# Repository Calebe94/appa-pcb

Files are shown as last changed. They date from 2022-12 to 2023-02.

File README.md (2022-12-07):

# Appa keyboard - PCB

This keyboard is inspired by [Plaid](https://github.com/AntonioPelayo/plaid-through-hole-keyboard) and [Gherkin Apls 1.1](https://www.40percent.club/2017/08/gherkin-alps-11.html).

I'm using white APLS switches for this project and Arduino Pro Mini as the core microcontroller.

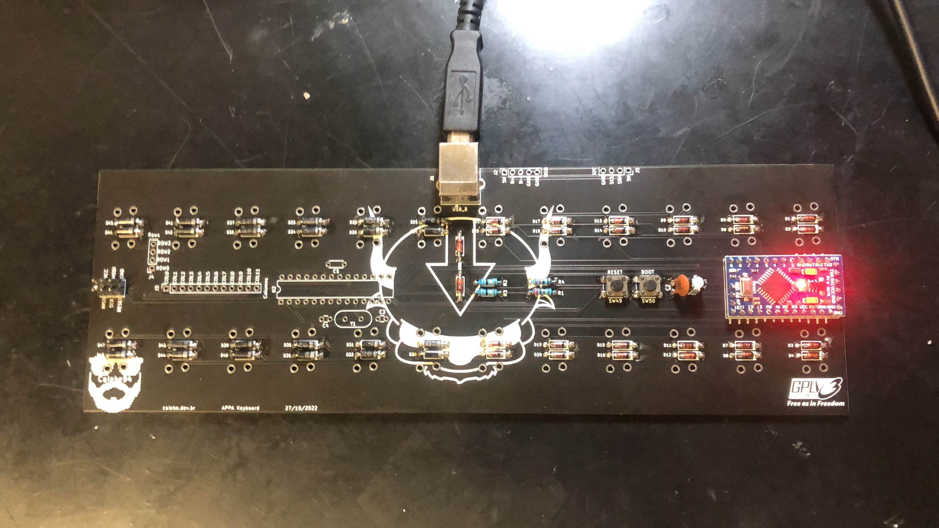
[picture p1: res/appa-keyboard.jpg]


## Dependencies

* [Kicad 6+](https://packages.debian.org/bookworm/kicad).

## Symbols and Footprints

* I'm using an slightly modded version of [ARDUINO PRO MINI](https://www.snapeda.com/parts/Arduino%20Pro%20Mini/Arduino/view-part/?t=arduino+pro+mini&welcome=home) from [SnapEDA](https://www.snapeda.com). (I've just added a couple of pins at the bottom at the board because my PRO Mini uses the TQFP and QFN/MLF package of the ATMEGA328p);
* For the ALPS switches and the diodes I'm using the [keyboard_parts.pretty](https://github.com/tmk/keyboard_parts.pretty) footprints;
* As for the rest I'm using the KiCAD's stock footprints.

## Schematic

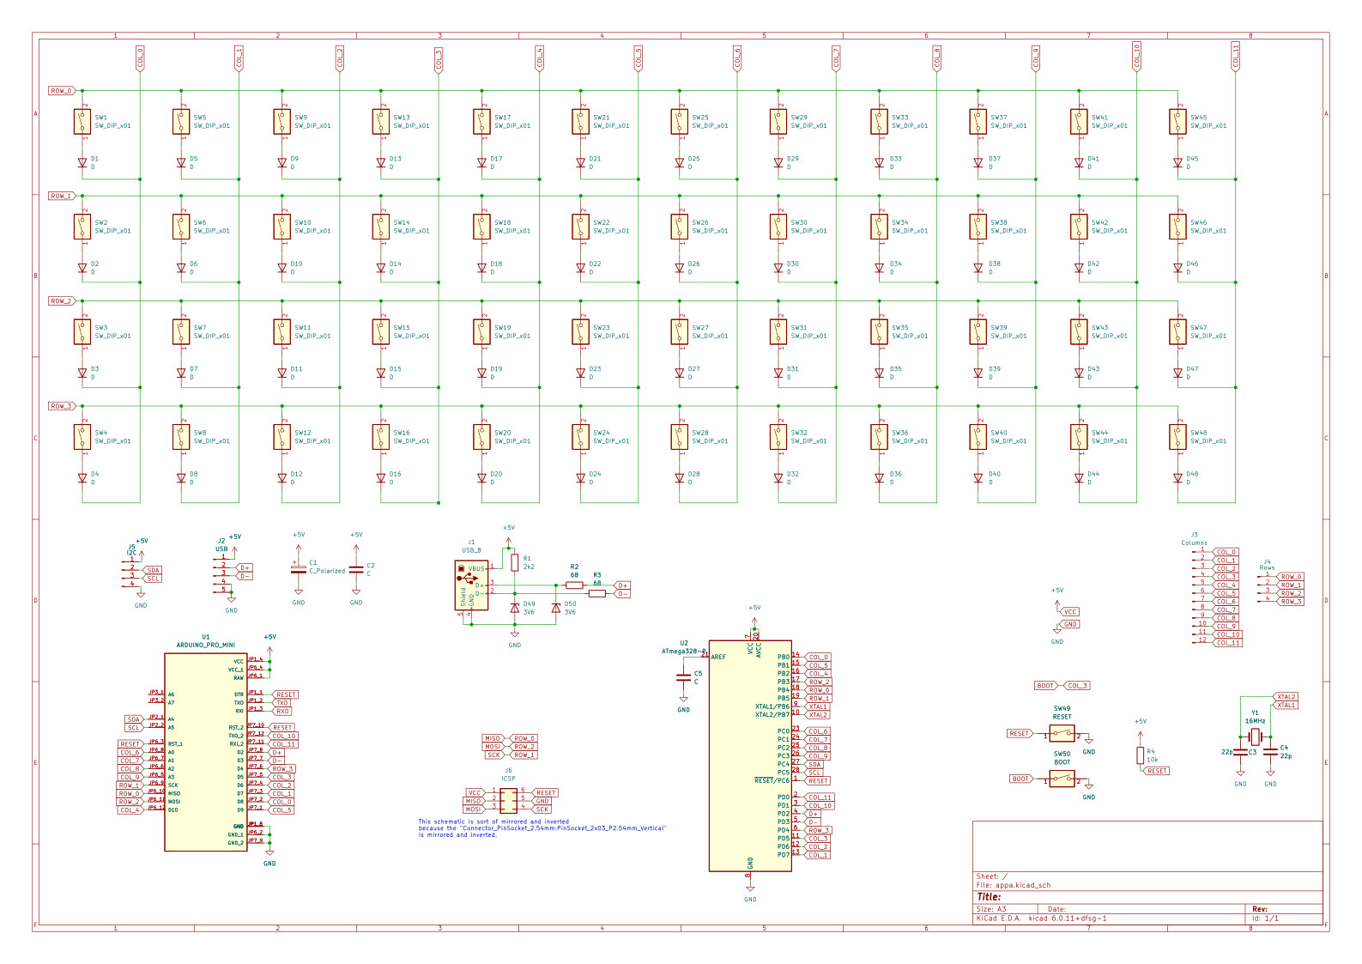
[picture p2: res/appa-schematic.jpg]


# License

All software is covered under [GNU General Public License v3.0](https://www.gnu.org/licenses/gpl-3.0.en.html).

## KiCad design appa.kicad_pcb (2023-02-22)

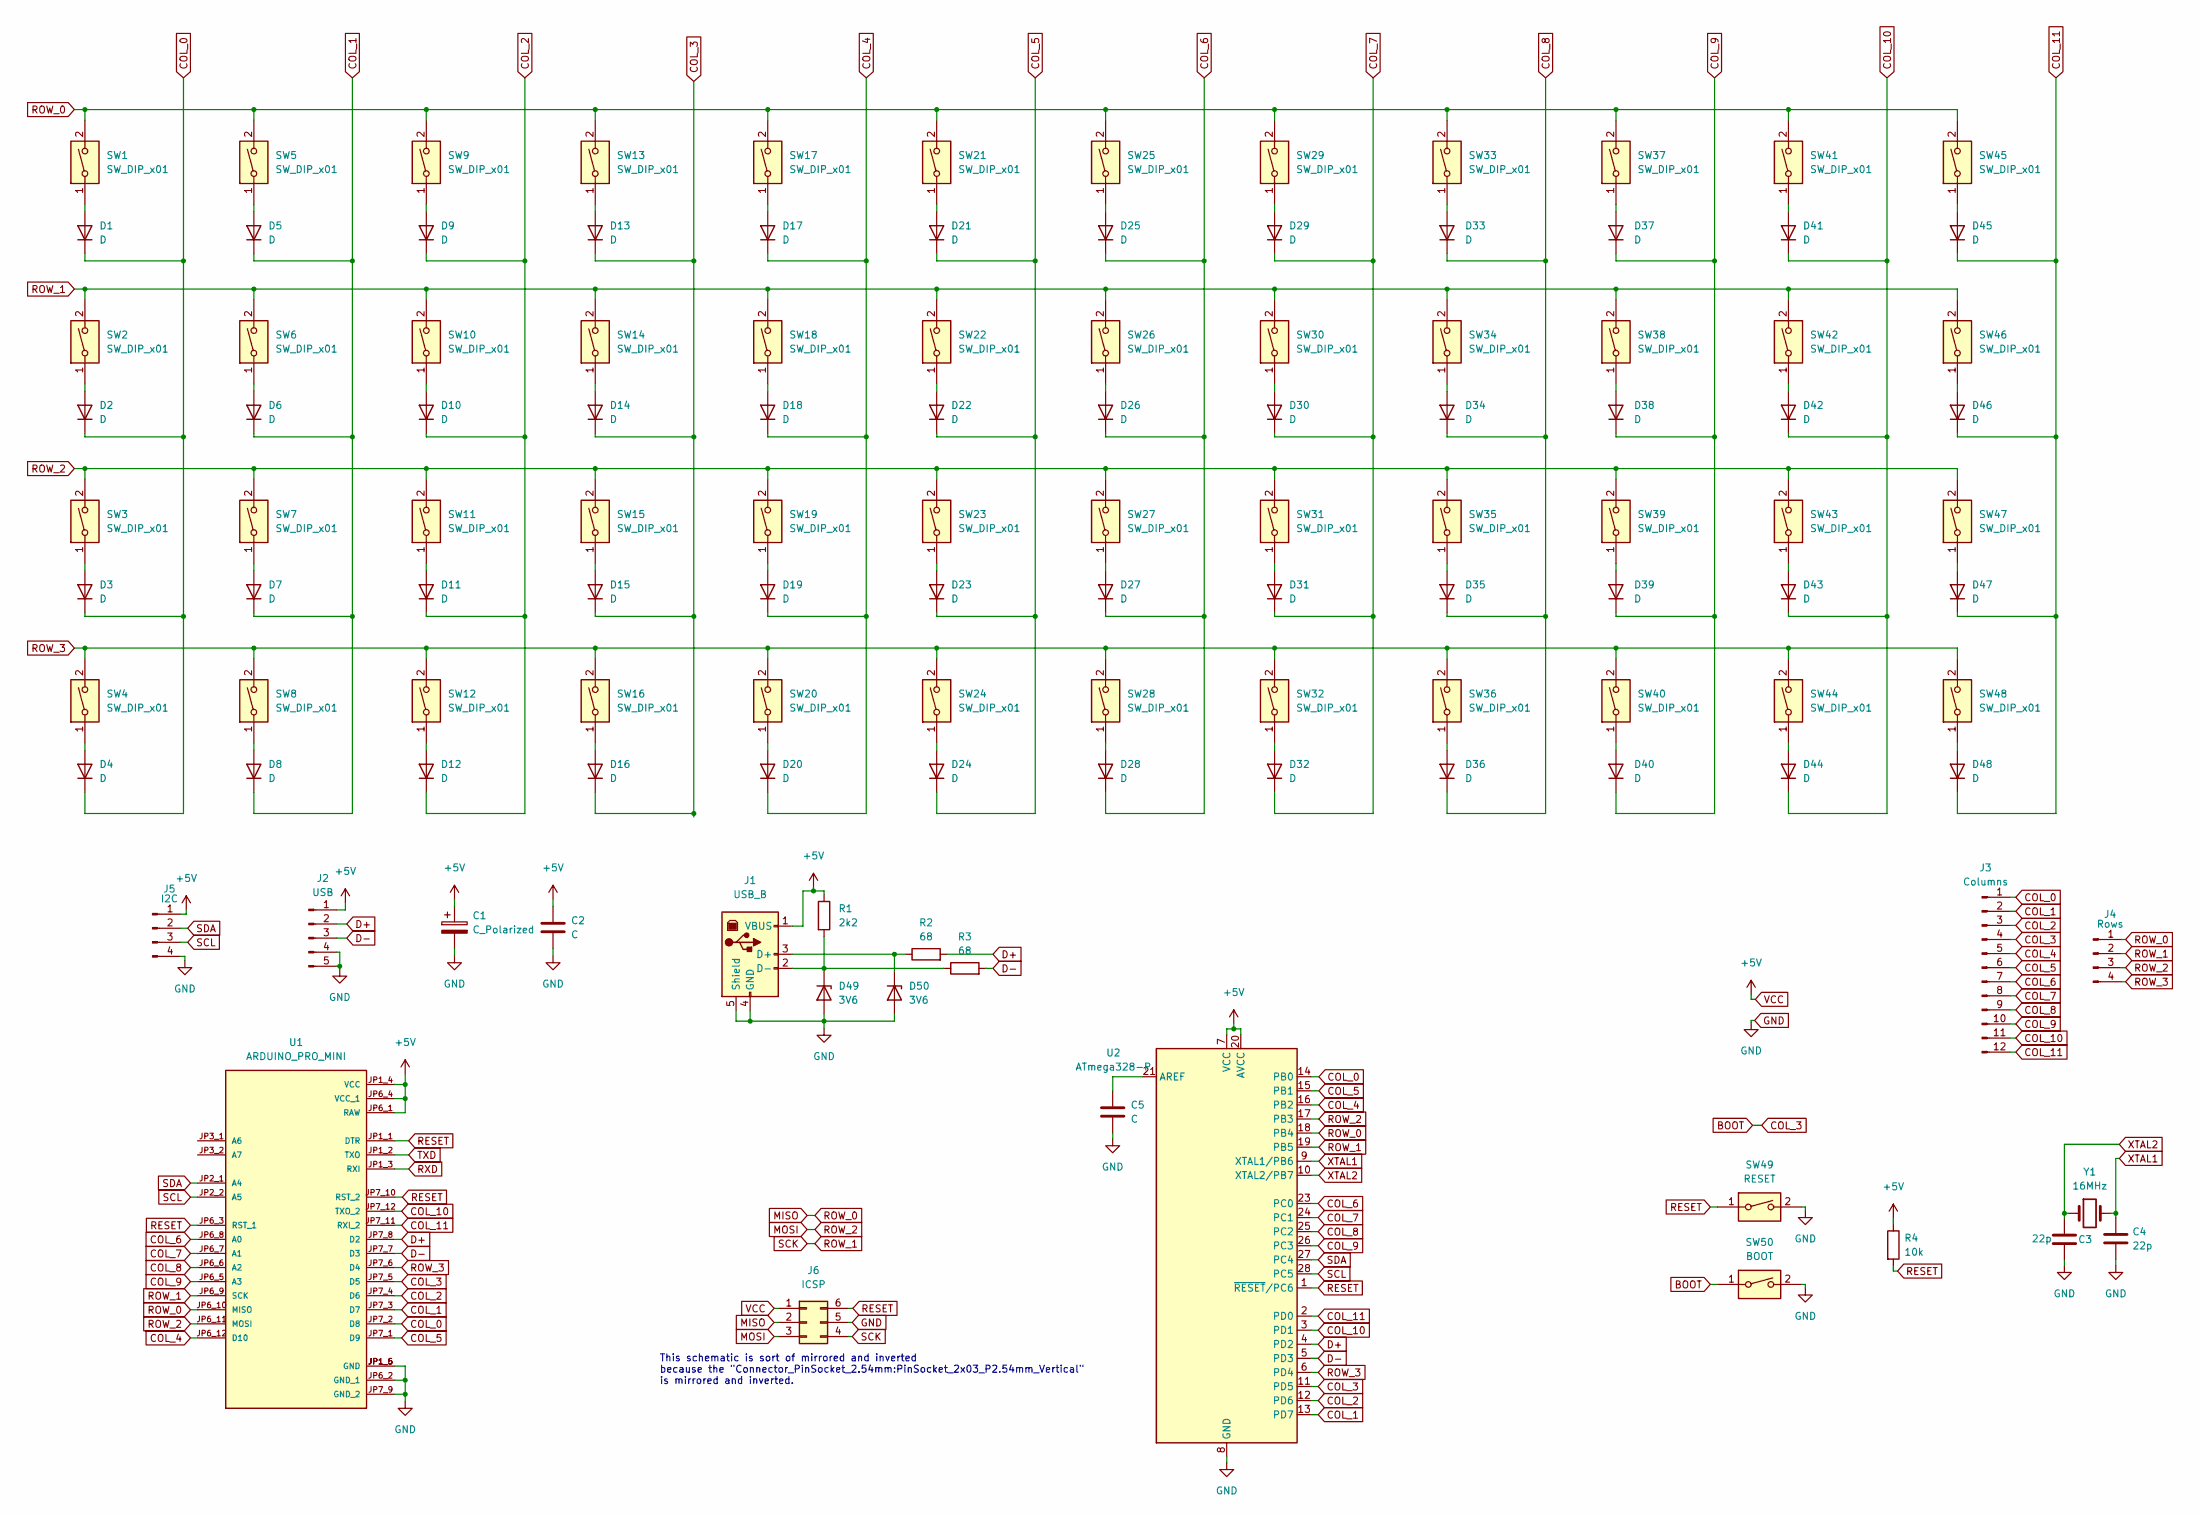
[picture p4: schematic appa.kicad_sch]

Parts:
C1: C_Polarized; CP_Radial_D4.0mm_P1.50mm
C2: C; C_Disc_D3.0mm_W1.6mm_P2.50mm
C3, C4: 22p; C_Disc_D3.0mm_W1.6mm_P2.50mm
C5: C; C_Disc_D4.3mm_W1.9mm_P5.00mm
D1, D2, D3, D4, D5, D6, D7, D8, D9, D10, D11, D12, D13, D14, D15, D16, D17, D18, D19, D20, D21, D22, D23, D24, D25, D26, D27, D28, D29, D30, D31, D32, D33, D34, D35, D36, D37, D38, D39, D40, D41, D42, D43, D44, D45, D46, D47, D48: D; D_SOD123_axial
D49, D50: 3V6; D_SOD123_axial
J1: USB_B; USB_B_OST_USB-B1HSxx_Horizontal
J2: USB; PinSocket_1x05_P2.54mm_Vertical
J3: Columns; PinSocket_1x12_P2.54mm_Vertical
J4: Rows; PinSocket_1x04_P2.54mm_Vertical
J5: I2C; PinSocket_1x04_P2.54mm_Vertical
J6: ICSP; PinSocket_2x03_P2.54mm_Vertical
R1: 2k2; R_Axial_DIN0204_L3.6mm_D1.6mm_P7.62mm_Horizontal
R2, R3: 68; R_Axial_DIN0204_L3.6mm_D1.6mm_P7.62mm_Horizontal
R4: 10k; R_Axial_DIN0204_L3.6mm_D1.6mm_P7.62mm_Horizontal
SW1, SW2, SW3, SW4, SW5, SW6, SW7, SW8, SW9, SW10, SW11, SW12, SW13, SW14, SW15, SW16, SW17, SW18, SW19, SW20, SW21, SW22, SW23, SW24, SW25, SW26, SW27, SW28, SW29, SW30, SW31, SW32, SW33, SW34, SW35, SW36, SW37, SW38, SW39, SW40, SW41, SW42, SW43, SW44, SW45, SW46, SW47, SW48: SW_DIP_x01; ALPS_SKCM
SW49: RESET; SW_PUSH_6mm
SW50: BOOT; SW_PUSH_6mm
U1: ARDUINO_PRO_MINI; MODULE_ARDUINO_PRO_MINI; PARTREV N/A
U2: ATmega328-P; DIP-28_W7.62mm
Y1: 16MHz; Crystal_HC18-U_Vertical

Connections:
BOOT: D13.1 (K), D14.1 (K), D15.1 (K), D16.1 (K), J3.4, SW50.1, U1.JP7_5 (D5), U2.11 (PD5)
COL_0: D1.1 (K), D2.1 (K), D3.1 (K), D4.1 (K), J3.1, U1.JP7_2 (D8), U2.14 (PB0)
COL_1: D5.1 (K), D6.1 (K), D7.1 (K), D8.1 (K), J3.2, U1.JP7_3 (D7), U2.13 (PD7)
COL_2: D9.1 (K), D10.1 (K), D11.1 (K), D12.1 (K), J3.3, U1.JP7_4 (D6), U2.12 (PD6)
COL_4: D17.1 (K), D18.1 (K), D19.1 (K), D20.1 (K), J3.5, U1.JP6_12 (D10), U2.16 (PB2)
COL_5: D21.1 (K), D22.1 (K), D23.1 (K), D24.1 (K), J3.6, U1.JP7_1 (D9), U2.15 (PB1)
COL_6: D25.1 (K), D26.1 (K), D27.1 (K), D28.1 (K), J3.7, U1.JP6_8 (A0), U2.23 (PC0)
COL_7: D29.1 (K), D30.1 (K), D31.1 (K), D32.1 (K), J3.8, U1.JP6_7 (A1), U2.24 (PC1)
COL_8: D33.1 (K), D34.1 (K), D35.1 (K), D36.1 (K), J3.9, U1.JP6_6 (A2), U2.25 (PC2)
COL_9: D37.1 (K), D38.1 (K), D39.1 (K), D40.1 (K), J3.10, U1.JP6_5 (A3), U2.26 (PC3)
COL_10: D41.1 (K), D42.1 (K), D43.1 (K), D44.1 (K), J3.11, U1.JP7_12 (TXO_2), U2.3 (PD1)
COL_11: D45.1 (K), D46.1 (K), D47.1 (K), D48.1 (K), J3.12, U1.JP7_11 (RXI_2), U2.2 (PD0)
D+: J2.2, R2.2, U1.JP7_8 (D2), U2.4 (PD2)
D-: J2.3, R3.2, U1.JP7_7 (D3), U2.5 (PD3)
GND: C1.2, C2.2, C3.2, C4.2, C5.2, D49.2 (A), D50.2 (A), J1.4 (GND), J1.5 (Shield), J2.4, J2.5, J5.4, J6.5, SW49.2, SW50.2, U1.JP1_5 (GND), U1.JP1_6 (GND), U1.JP6_2 (GND_1), U1.JP7_9 (GND_2), U2.8 (GND), U2.22 (GND)
MISO: J4.1, J6.2, SW1.2, SW5.2, SW9.2, SW13.2, SW17.2, SW21.2, SW25.2, SW29.2, SW33.2, SW37.2, SW41.2, SW45.2, U1.JP6_10 (MISO), U2.18 (PB4)
MOSI: J4.3, J6.3, SW3.2, SW7.2, SW11.2, SW15.2, SW19.2, SW23.2, SW27.2, SW31.2, SW35.2, SW39.2, SW43.2, SW47.2, U1.JP6_11 (MOSI), U2.17 (PB3)
unnamed: C5.1, U2.21 (AREF)
unnamed: D1.2 (A), SW1.1
unnamed: D2.2 (A), SW2.1
unnamed: D3.2 (A), SW3.1
unnamed: D4.2 (A), SW4.1
unnamed: D5.2 (A), SW5.1
unnamed: D6.2 (A), SW6.1
unnamed: D7.2 (A), SW7.1
unnamed: D8.2 (A), SW8.1
unnamed: D9.2 (A), SW9.1
unnamed: D10.2 (A), SW10.1
unnamed: D11.2 (A), SW11.1
unnamed: D12.2 (A), SW12.1
unnamed: D13.2 (A), SW13.1
unnamed: D14.2 (A), SW14.1
unnamed: D15.2 (A), SW15.1
unnamed: D16.2 (A), SW16.1
unnamed: D17.2 (A), SW17.1
unnamed: D18.2 (A), SW18.1
unnamed: D19.2 (A), SW19.1
unnamed: D20.2 (A), SW20.1
unnamed: D21.2 (A), SW21.1
unnamed: D22.2 (A), SW22.1
unnamed: D23.2 (A), SW23.1
unnamed: D24.2 (A), SW24.1
unnamed: D25.2 (A), SW25.1
unnamed: D26.2 (A), SW26.1
unnamed: D27.2 (A), SW27.1
unnamed: D28.2 (A), SW28.1
unnamed: D29.2 (A), SW29.1
unnamed: D30.2 (A), SW30.1
unnamed: D31.2 (A), SW31.1
unnamed: D32.2 (A), SW32.1
unnamed: D33.2 (A), SW33.1
unnamed: D34.2 (A), SW34.1
unnamed: D35.2 (A), SW35.1
unnamed: D36.2 (A), SW36.1
unnamed: D37.2 (A), SW37.1
unnamed: D38.2 (A), SW38.1
unnamed: D39.2 (A), SW39.1
unnamed: D40.2 (A), SW40.1
unnamed: D41.2 (A), SW41.1
unnamed: D42.2 (A), SW42.1
unnamed: D43.2 (A), SW43.1
unnamed: D44.2 (A), SW44.1
unnamed: D45.2 (A), SW45.1
unnamed: D46.2 (A), SW46.1
unnamed: D47.2 (A), SW47.1
unnamed: D48.2 (A), SW48.1
unnamed: D49.1 (K), J1.2 (D-), R1.2, R3.1
unnamed: D50.1 (K), J1.3 (D+), R2.1
RESET: J6.6, R4.2, SW49.1, U1.JP1_1 (DTR), U1.JP6_3 (RST_1), U1.JP7_10 (RST_2), U2.1 (~RESET/PC6)
ROW_1: J4.2, J6.4, SW2.2, SW6.2, SW10.2, SW14.2, SW18.2, SW22.2, SW26.2, SW30.2, SW34.2, SW38.2, SW42.2, SW46.2, U1.JP6_9 (SCK), U2.19 (PB5)
ROW_3: J4.4, SW4.2, SW8.2, SW12.2, SW16.2, SW20.2, SW24.2, SW28.2, SW32.2, SW36.2, SW40.2, SW44.2, SW48.2, U1.JP7_6 (D4), U2.6 (PD4)
RXD: U1.JP1_3 (RXI)
SCL: J5.3, U1.JP2_2 (A5), U2.28 (PC5)
SDA: J5.2, U1.JP2_1 (A4), U2.27 (PC4)
TXD: U1.JP1_2 (TXO)
VCC: C1.1, C2.1, J1.1 (VBUS), J2.1, J5.1, J6.1, R1.1, R4.1, U1.JP1_4 (VCC), U1.JP6_1 (RAW), U1.JP6_4 (VCC_1), U2.7 (VCC), U2.20 (AVCC)
XTAL1: C4.1, U2.9 (XTAL1/PB6), Y1.2
XTAL2: C3.1, U2.10 (XTAL2/PB7), Y1.1

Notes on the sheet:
This schematic is sort of mirrored and inverted because the "Connector_PinSocket_2.54mm:PinSocket_2x03_P2.54mm_Vertical" is mirrored and inverted.

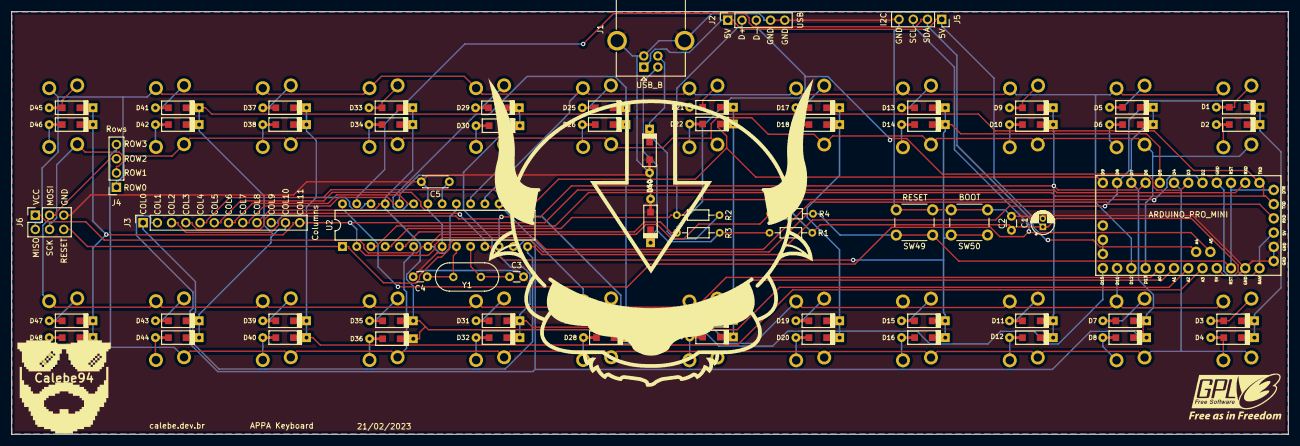
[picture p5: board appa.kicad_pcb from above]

Board: 2 copper layers, 227.8 x 75.4 mm, 120 parts (0 on the bottom side), 76 nets.

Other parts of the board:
Calebe94: Calebe94; calebe94
G1: LOGO; gpl3

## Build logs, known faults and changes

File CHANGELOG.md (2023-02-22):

# Changelog

All notable changes to this project will be documented in this file.

The format is based on [Keep a Changelog](https://keepachangelog.com/en/1.0.0/),
and this project adheres to [Semantic Versioning](https://semver.org/spec/v2.0.0.html).

## [Unreleased]

### Added

### Fixed

### Changed

### Removed

## [1.1.0]

### Added

### Fixed

* Fixed `BOOT` button that was not wired to the microcontroller [#1](https://github.com/Calebe94/appa-pcb/issues/1);
* Fixed `COL_10` and `COL_11` that was not wired to the microcontroller [#2](https://github.com/Calebe94/appa-pcb/issues/2); 
* Added `res/appa-schematic.svg` file;

### Changed

### Removed

* Removed `appa.jpg` file because there is already a schematic file in the `res/` folder;
* Removed `fp-info-cache` file;
* Removed `gerber/` folder;

## [1.0.1]

### Added

* Added `.github` folder with [Github Templates](https://docs.github.com/en/communities/using-templates-to-encourage-useful-issues-and-pull-requests/configuring-issue-templates-for-your-repository);

### Fixed

### Changed

* Updated changelog;

### Removed

## [1.0.0]

### Added

* Added schematic as a `.svg` image;
* Added GPL3+ license file;
* Added Appa and my logo as silk;
* Added the `gerber` folder to ship the gerber files on tags;
* Added GPL3+ license logo as silk;
* Added `ATMEGA328p` standalone circuit as a redundancy;
* Added `gerber/` folder;
* Added `GPL3.svg` logo;
* Added `fp-info-cache` file;

### Fixed

### Changed

* Updated readme with some relevant informations;
* Changed switches layout to be read from left to right on the PCB;

### Removed

[unreleased]: https://github.com/Calebe94/appa-pcb/compare/1.1.0...HEAD
[1.1.0]: https://github.com/Calebe94/appa-pcb/compare/1.0.1...1.1.0
[1.0.1]: https://github.com/Calebe94/appa-pcb/compare/1.0.0...1.0.1
[1.0.0]: https://github.com/Calebe94/appa-pcb/releases/tag/1.0.0

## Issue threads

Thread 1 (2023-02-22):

BOOT button is not wired to microcontroller

Calebe94, 2023-02-22:
<!--- Provide a general summary of the issue in the Title above -->

## Expected Behavior
<!--- Tell us what should happen -->

The `BOOT` button should be wired to the same pin as `COL_3` is wired. Which is the `PD5` from ATMEGA328 and `D5` from Arduino Pro Mini.

## Current Behavior
<!--- Tell us what happens instead of the expected behavior -->

BOOT button is not wired to microcontroller.

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

Closed 2023-02-22.

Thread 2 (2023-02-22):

COL_10 and COL_11 are not wired to ATMEGA328

Calebe94, 2023-02-22:
<!--- Provide a general summary of the issue in the Title above -->

## Expected Behavior
<!--- Tell us what should happen -->

The `COL_10` and `COL_11` should be wired to `PD0` and `PD1` pins respectively.

## Current Behavior
<!--- Tell us what happens instead of the expected behavior -->

`COL_10` and `COL_11` are not wired to ATMEGA328

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

Closed 2023-02-22.

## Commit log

2022-10-25 Changed routes
    [Calebe94.kicad_pcb, Calebe94.kicad_sch]
2022-10-26 Added appa and my logo as silk
    [Calebe94.kicad_pcb, Calebe94.kicad_sch]
2022-10-26 Changed switches layout to be read from left to right
    [Calebe94.kicad_pcb]
2022-10-27 Added schematic and updated readme
2022-10-28 Added atmega328 standalone schematic
2022-10-28 Added gerber folder
    [Calebe94-B_Cu.gbr, Calebe94-B_Mask.gbr, Calebe94-B_Paste.gbr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]
2022-11-09 Added BOM
    [Calebe94.csv]
2022-12-07 Updated README
    - Renamed project;
    - Changed schematic image to `.jpeg`;
    - Added keyboard picture.
2022-12-07 Removed BOM file
    [Calebe94.csv]
2022-12-07 Renamed project to appa
    [appa.kicad_pcb, appa.kicad_sch]
2023-02-22 Fixed unwired pins
    [appa.kicad_pcb, appa.kicad_sch]
2023-02-22 Removed gerber folder
    [Calebe94-B_Cu.gbr, Calebe94-B_Mask.gbr, Calebe94-B_Paste.gbr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]
